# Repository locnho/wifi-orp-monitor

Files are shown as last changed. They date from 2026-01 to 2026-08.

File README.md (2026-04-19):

# WiFi Pool ORP Monitor Device

This project provides a WiFi Pool ORP Monitor device using the following parts:

  * Seeed Studio XIAO ESP32C6 with WiFi support external antenna
  * 0.96" LCD Display
  * Rotary Switch
  * Atlas Lab Grade GOLD ORP Probe
  * Atlas EZO ORP Circuit Board
  * Atlas EZO Carrier Board
  * Custom connection board to connect them
  * 3D print housing with nylon 2.5mm hex spacer/screws

**IMPORTANT:** For salt water pool, you must use the GOLD ORP type probe.

The device will send ORP reading from Atlas probe to a MQTT broker. By default it is configured to send ORP reading to AquaLinkD ORP. Though, you should be able to publish any message to MQTT broker.

# How To Assemble the ORP Monitor Device

After you have printed the mounting housing (from folder models), perform the following steps:

  1. Attach 35MM DIN rail bracket to base plate
  2. Attach some on 6 holes nylon spacer (3mm or so)
  3. Attach the Atlas EZO Carrier Board with some nylon spacer. Did not measured the spacer height.
  4. Attach the Atlas ORP Circuit Board
  5. Make a custom board to house the ESP32C6 with three JST connectors. Then drill holes using the 3D printed template. JST connectors are 3 pins, 4 pins and 5 pins. For the ESP32C6, it is attached to 2.54mm Female Pin Header Socket Connector. This allows connecting the rotary, LCD, and Atlas RS232 to the ESP32C6 board. All you need is Vcc, GND, Rx, Tx, I2C, and some digital pin. For pin, see the Ardiuno source code. Attach the external WiFi antenna. See the image below. This is the green board.
  6. Attach some nylon spacer (did not measuer the spacer height)
  7. Slide the side cover in. The total height should be equal to the cover height.
  8. Create connector wire and attach them
  9. Attach the LCD to the top board with some nylone screws (2mm screw)
  10. Screw in some nylon screws

Better to see images below.

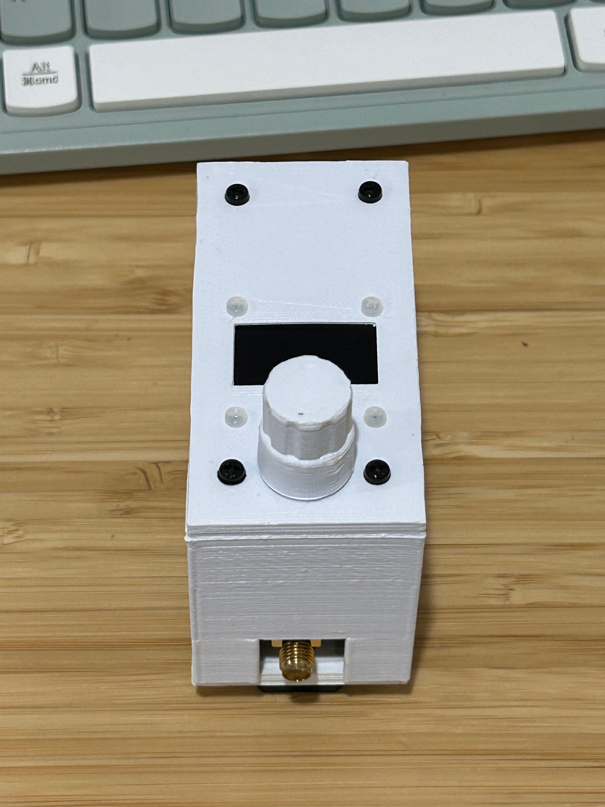
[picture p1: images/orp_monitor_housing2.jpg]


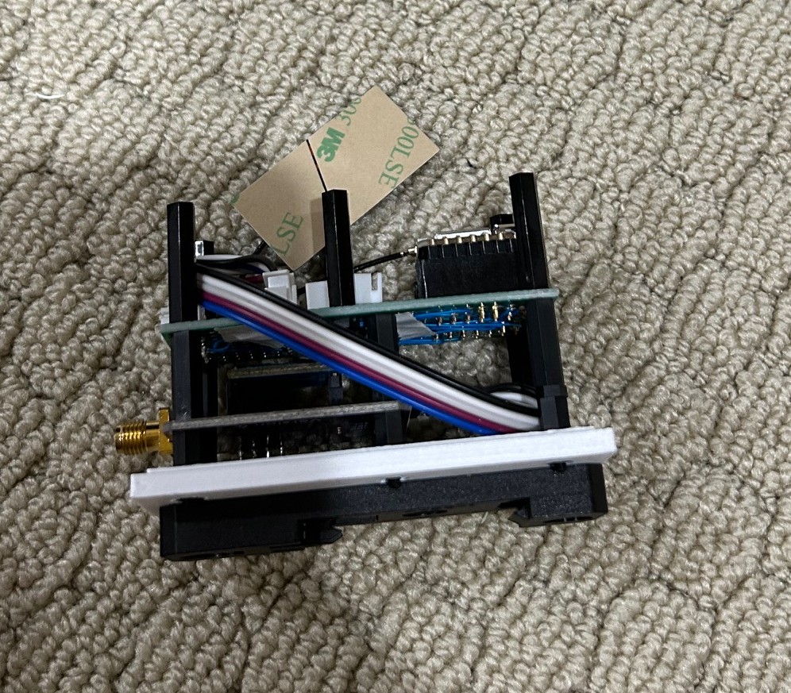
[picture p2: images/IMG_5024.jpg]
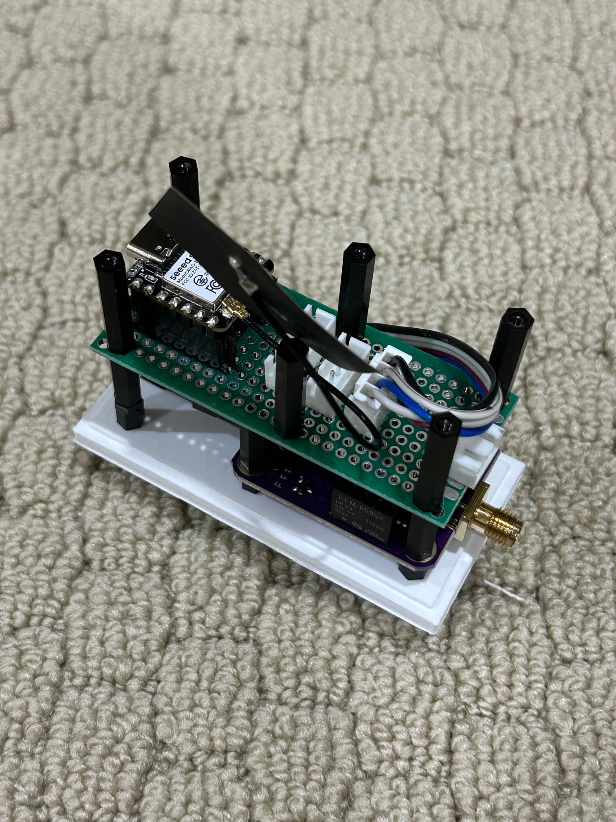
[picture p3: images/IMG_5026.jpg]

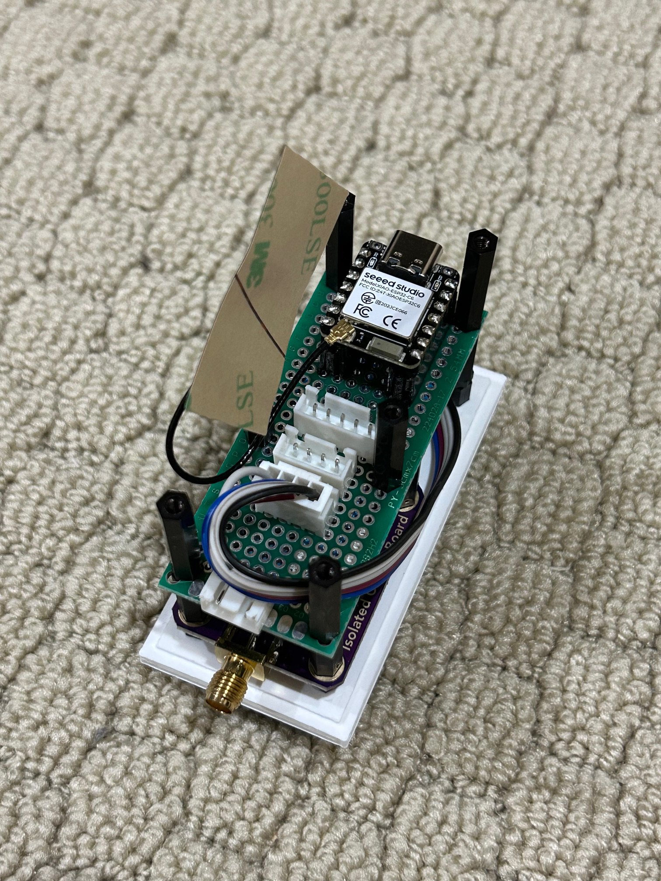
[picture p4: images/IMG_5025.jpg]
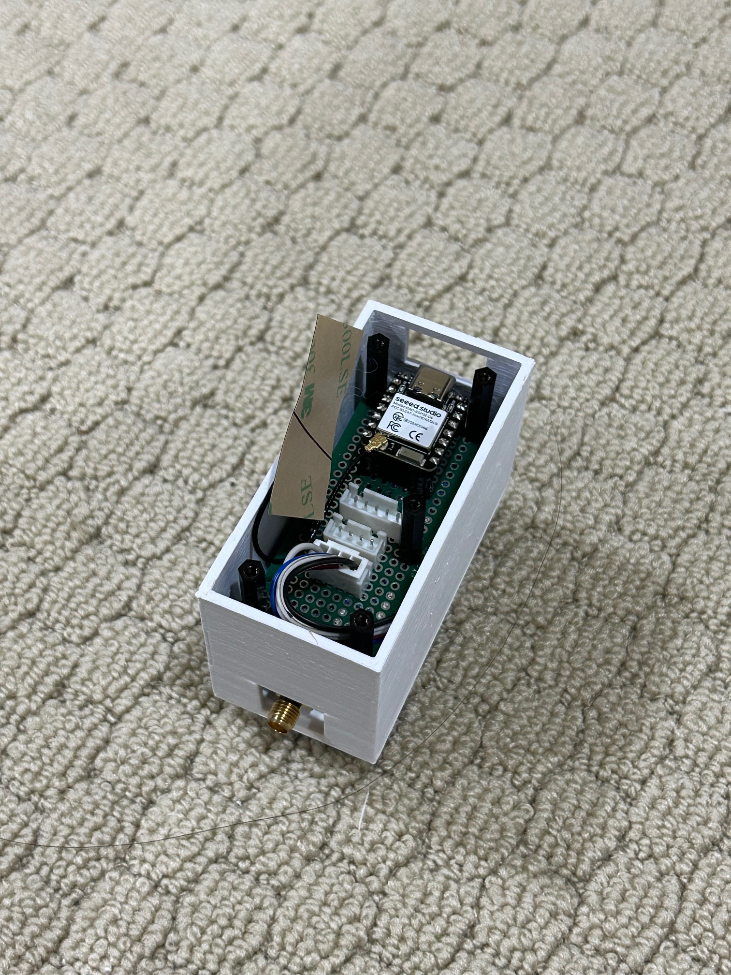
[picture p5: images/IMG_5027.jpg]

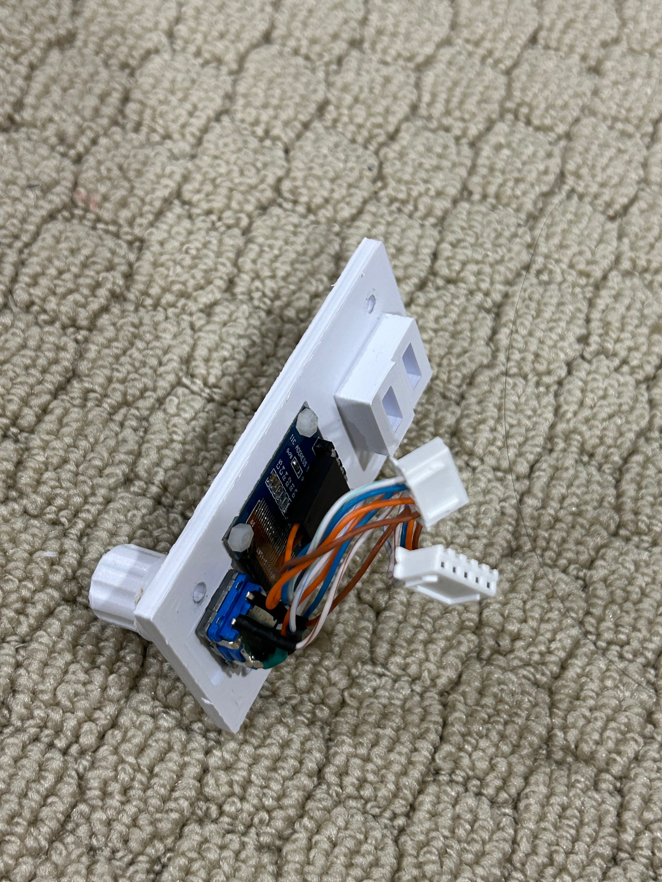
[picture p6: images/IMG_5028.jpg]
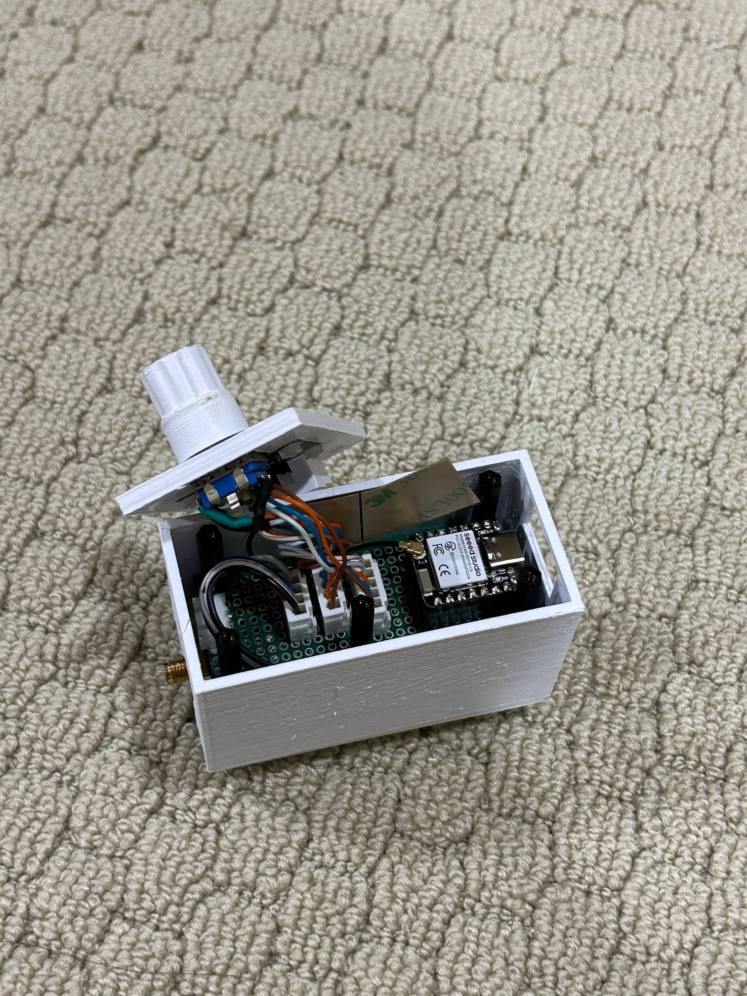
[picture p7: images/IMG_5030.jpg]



# How To Configure WiFi

After you have programmed the arduino code using Arduino IDE, perform the following steps:

  * Download the SmartConfig app. For iPhone, it is called "SmartConnect". Then start the app and set your WiFi password with the app.
  * On the ORP device, connect USB power
  * Press the button to enter menu
  * Select "WiFi Setup" and push the button
  * On the app, tap to start WiFi configuration

After this, wait around 2 to 3 minutes on the mobile app. This will configure the WiFi network and password.

# How To Configure System Setting

To configure system setting such as MQTT broker, ORP calibrate value, etc, open a browser and enter the IP address as ``http://<ip address>``.

You should see the below image. Configure the host name, MQTT Server name, user, password, port, and topic.

If the pump is not running, ORP value of 0.0 is reported using the ``MQTT Pump Topic``. If you want to always report ORP reading even if pump is not running, set to blank.

If your ORP calibration solution isn't 225 mV, change the ORP calibration value. Then click on the ``Submit`` button.

If you want this device to control the SWG percentage, check the box "Enable SWG Change:".

The Auto SWG algorithm is as follow:

 1. Delay for specified hours. This is configured via "SWG Control Delay Time (hrs)".
 2. Measure the ORP for at least specified hours. This is configured via "SWG Control Measure Time (hrs)". Until there is this specified measured time, the sample is not consider valid.
 3. After the sample is measured for specified hours, compute the sample average for that day.
 4. If the sample is below ORP target, schedule the SWG for next day.
 5. Once the avarge sample for that day is below specified target, schedule the SWG for next day.
 6. Run the SWG at specified percentage for specified time.

Given that the algorithm is based on day average, a date is required. The date is acquired using the NTP server. You must configures the NTP server and time zone.

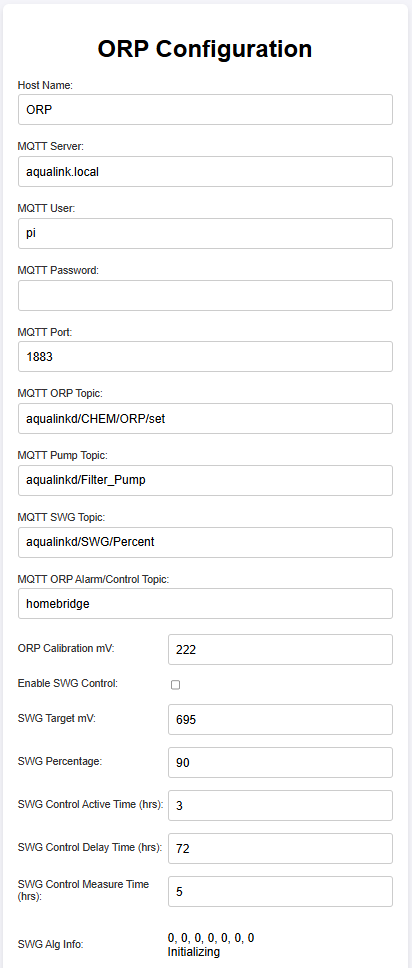
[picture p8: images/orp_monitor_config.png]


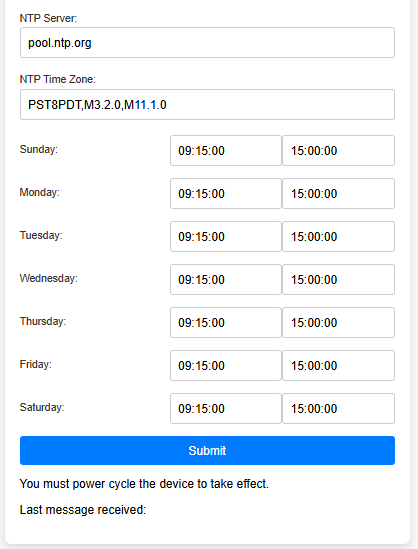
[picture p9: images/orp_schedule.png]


# How To Calibrate GOLD ORP Probe

To calibrate ORP probe, perform these steps:

  1. Push the button
  2. Select "CAL ORP" and push the knob to start ORP calibration

# How to Read the LCD Screen

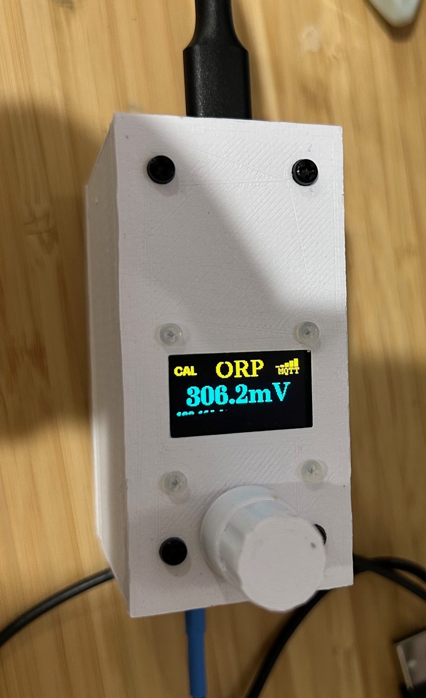
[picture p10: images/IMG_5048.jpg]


The "C" indicates that the ORP has been calibrated. If there is an X over it, then it is not calibrated.

The "P" indicates that the pump is running. If there is an X over it, then the pump is not running. This is based on MQTT message from MQTT pump topic. If the MQTT pump topic is blank, then it is assumed that the pump is always running.

The upper right WiFi bar indicate the WiFi RSSI strength.

The "MQTT" indicates that it is connected to a MQTT broker.

The first line reading shows:

  * ORP reading as from Atlas GOLD probe
  * Percentage of the SWG (if enabled support)

The second line reading shows:

  * ORP reading as computed
  * SWG percent this device configured the SWG via MQTT
  * Status code of the Auto SWG

The Status code of the Auto SWG are:

  * I - Initializing
  * D - Delay in-progress
  * S - Scheduling Auto SWG for next day
  * M - Measuring the ORP (per day) 
  * A - Auto SWG is active at specified percentage

The screen will turn off after some idle time. Press the button to show the screen.

Here is an image as reported via AquaLinkD.



If you want to disable 'Auto SWG', you can do the following:

  1. Disable via the web site configuration
  2. Disable via the MQTT Homebridge device or HomeKit using the 'Auto SWG'

Please note when disable from 'Auto SWG', it does not persist across a power cycle.

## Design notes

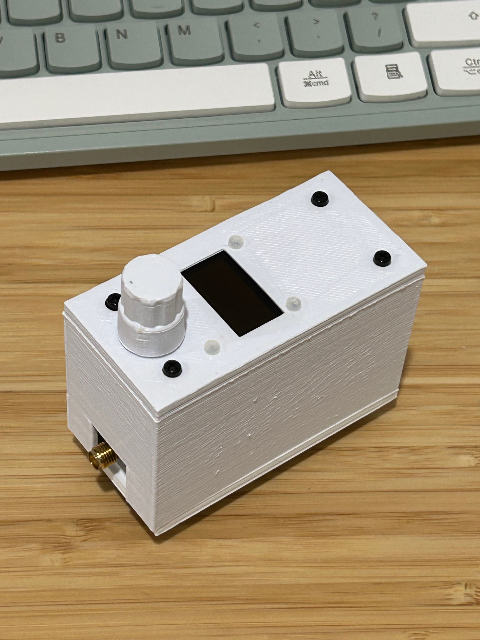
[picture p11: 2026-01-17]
images/orp_monitor_housing1.jpg

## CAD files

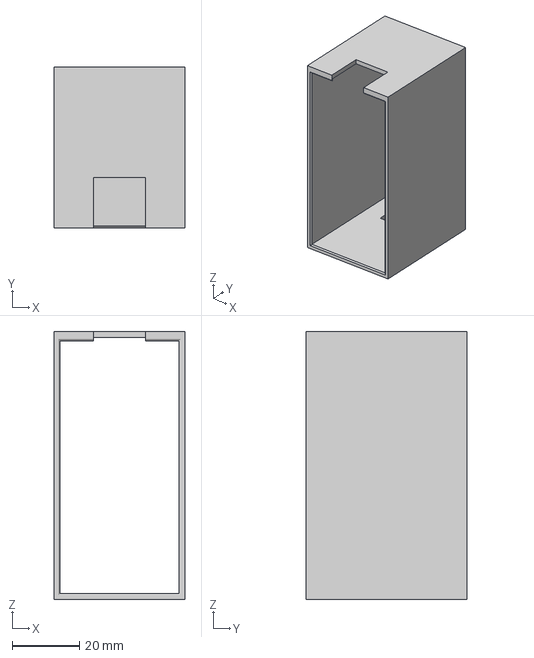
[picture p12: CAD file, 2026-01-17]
models/ORP-Side.3mf
39.0 x 48.0 x 80.0 mm

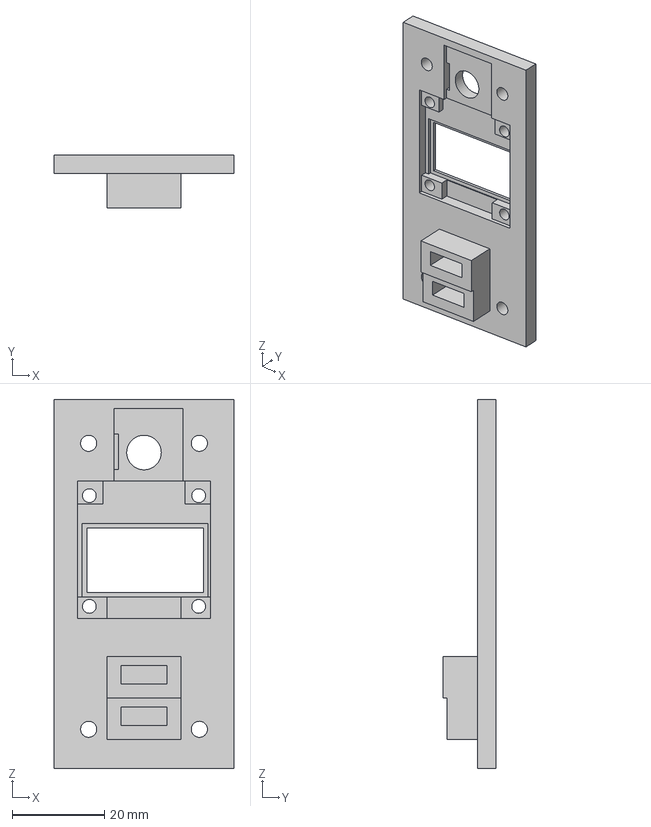
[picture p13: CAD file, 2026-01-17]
models/ORP-Top.3mf
39.0 x 11.5 x 80.0 mm

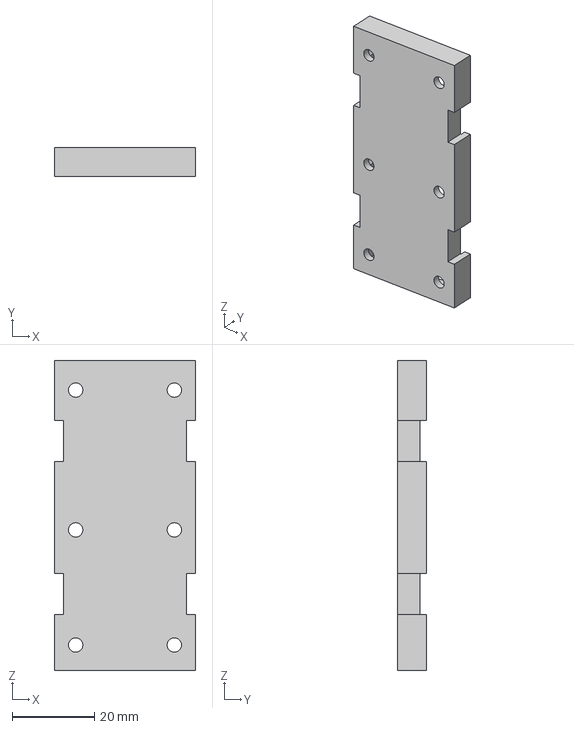
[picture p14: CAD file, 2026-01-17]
models/ORP-Drill-Plate.3mf
34.4 x 7.00 x 75.4 mm

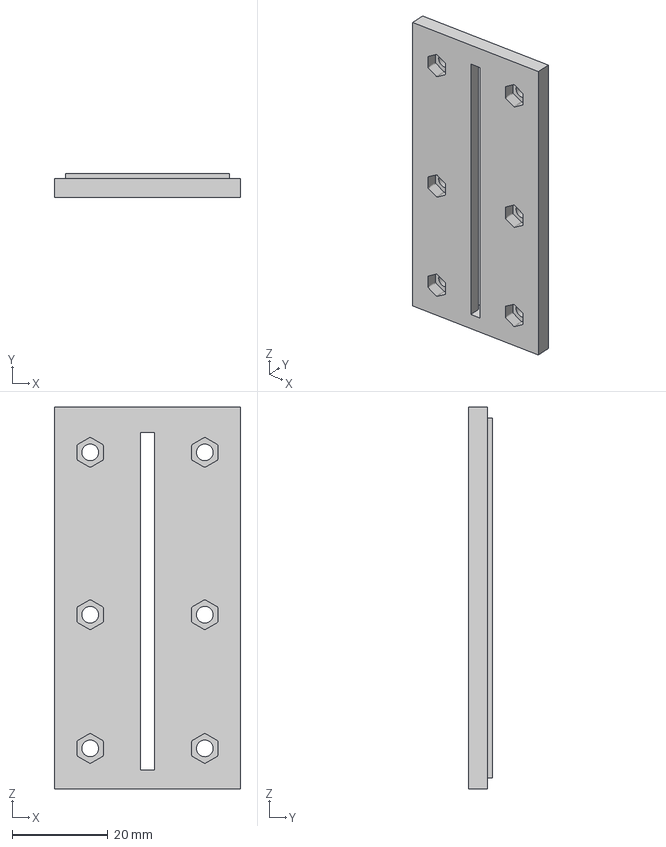
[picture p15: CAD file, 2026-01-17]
models/DIN-Rail-ORP-Base.3mf
39.0 x 5.00 x 80.0 mm

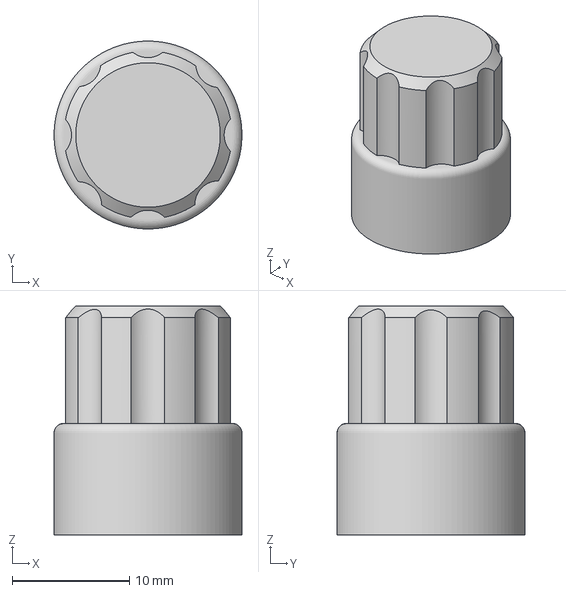
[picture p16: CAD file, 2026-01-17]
models/Rotary-Knob.3mf
16.0 x 16.0 x 19.5 mm

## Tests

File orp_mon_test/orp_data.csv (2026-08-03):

Date | orp | swg | alarm | ph
1770663612 | 574.7 | 55 | 1 | 0
1770663642 | 574.6 | 55 | 1 | 0
1770663672 | 574.4 | 55 | 1 | 0
1770663732 | 574.3 | 55 | 1 | 0
1770663762 | 574.4 | 55 | 1 | 0
1770663792 | 574.6 | 55 | 1 | 0
1770663822 | 574.4 | 55 | 1 | 0
1770663852 | 574.3 | 55 | 1 | 0
1770663882 | 574.4 | 55 | 1 | 0
1770663912 | 574.3 | 55 | 1 | 0
1770663942 | 573.9 | 55 | 1 | 0
1770663972 | 574.1 | 55 | 1 | 0
1770664002 | 573.8 | 55 | 1 | 0
1770664032 | 573.7 | 55 | 1 | 0
1770664092 | 573.6 | 55 | 1 | 0
1770664122 | 573.1 | 55 | 1 | 0
1770664152 | 573.3 | 55 | 1 | 0
1770664182 | 573.1 | 55 | 1 | 0
1770664212 | 573.2 | 55 | 1 | 0
1770664242 | 572.8 | 55 | 1 | 0
1770664272 | 572.9 | 55 | 1 | 0
1770664332 | 572.8 | 55 | 1 | 0
1770664362 | 572.7 | 55 | 1 | 0
1770664392 | 572.6 | 55 | 1 | 0
1770664422 | 572.5 | 55 | 1 | 0
1770664452 | 572.3 | 55 | 1 | 0
1770664482 | 572.2 | 55 | 1 | 0
1770664512 | 572.1 | 55 | 1 | 0
1770664542 | 572.0 | 55 | 1 | 0
1770664572 | 571.9 | 55 | 1 | 0
1770664602 | 571.7 | 55 | 1 | 0
1770664632 | 571.3 | 55 | 1 | 0
1770664692 | 571.2 | 55 | 1 | 0
1770664722 | 571.0 | 55 | 1 | 0
1770664752 | 570.8 | 55 | 1 | 0
1770664782 | 570.6 | 55 | 1 | 0
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

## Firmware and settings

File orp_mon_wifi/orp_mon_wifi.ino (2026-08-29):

/*
 * ORP Monitor
 *
 */
#define WIFI_SUPPORT 1
#define WIFI_EXTERNAL_ANTENNA 1

#if defined(WIFI_SUPPORT) && (defined(ARDUINO_SEEED_XIAO_ESP32C3) || defined(ARDUINO_ARCH_ESP32) || defined(ARDUINO_SEEED_XIAO_ESP32C6))
#else
  #undef WIFI_SUPPORT
#endif

#include "Button2.h"
#include "Rotary.h"
#include <U8g2lib.h>
#include <Wire.h>
#include <HardwareSerial.h>

#define DBG_SUPPORT 1         /* Print general debug information */
//#define DBG_STATUS 1        /* Print equivalent of menu on serial port */
//#define DBG_MQTT 1          /* Print MQTT messages */
#define DBG_ORP 1             /* Print ORP message */
//#define SKIP_MQTT_PUBLISH 1   /* Set to 1 to skip publish any MQTT message - use for testing without actual control SWG */

#if defined(DBG_SUPPORT)
  #define DBG_PRINT   Serial.print
  #define DBG_PRINTLN Serial.println
#else
  #define DBG_PRINT(x)
  #define DBG_PRINTLN(x)
#endif

#if defined(DBG_STATUS)
  #define STATUS_PRINT   Serial.print
  #define STATUS_PRINTLN Serial.println
#else
  #define STATUS_PRINT(x)
  #define STATUS_PRINTLN(x)
#endif

#if defined(DBG_ORP)
  #define ORP_PRINT   Serial.print
  #define ORP_PRINTLN Serial.println
#else
  #define ORP_PRINT(x)
  #define ORP_PRINTLN(x)
#endif

#if defined(DBG_MQTT)
  #define MQTT_PRINT   Serial.print
  #define MQTT_PRINTLN Serial.println
#else
  #define MQTT_PRINT(x)
  #define MQTT_PRINTLN(x)
#endif

#define FW_VERSION    "0.7"

//
// Rotary and Button
#define ROTARY_PIN1	2
#define ROTARY_PIN2	1
#define BUTTON_PIN	A0
#define CLICKS_PER_STEP   4   // this number depends on your rotary encoder 
Rotary rotary;
Button2 button;

//
// OELD
U8G2_SSD1306_128X64_NONAME_F_HW_I2C u8g2(U8G2_R0, /* reset=*/ U8X8_PIN_NONE);
int oled_addr = 0x3C;
bool oled_detected = 0;
unsigned long oled_idle_ts = 0;
bool oled_idle = 0;
unsigned long oled_refresh_ts = 0;
unsigned long oled_alive = 0;
#define OLED_IDLE_TIMEOUT_MS      (2*60000)
bool oled_screen_refresh = 0;

//
// Status message
char status_msg[40];
unsigned long status_msg_ts = 0;

//
// ORP Info
char orp_line[80];
int orp_line_cnt = 0;
float orp_reading = 0.0;
unsigned long ord_ts = 0;
int orp_caled = -1;
unsigned long orp_cal_ts = 0;
unsigned long orp_query_ts = 0;
enum ORP_STATE {
  OP_ORP_READING = 1,
  OP_ORP_CAL_INIT,
  OP_ORP_CAL_RESPONSE,
};
enum ORP_STATE orp_state = OP_ORP_READING;
HardwareSerial orp_serial(0);

//
// Operation State
enum OP_STATE {
  OP_NORMAL = 0,
  OP_MENU,
  OP_ORP_CAL,
  OP_WIFI_SETUP,
  OP_MQTT_CONNECT,
  OP_SETTING_INFO,
};

enum OP_STATE op_state = OP_NORMAL;

//
// WiFi
#if defined(WIFI_SUPPORT)
#include "sdkconfig.h"
#include "WiFi.h"
#include <ArduinoMDNS.h>
#include "time.h"
#include "esp_sntp.h"

typedef struct {
  uint32_t signature1;
  uint32_t signature2;
  char ssid[64];
  char password[64];
  char hostname[64];
  char mqtt_broker[64];
  char mqtt_topic[64];
  char mqtt_user[64];
  char mqtt_password[64];
  char mqtt_pump_topic[64];
  char mqtt_swg_topic[64];
  char mqtt_orp_alarm_topic[64];
  char mqtt_datetime_topic[64];
  int mqtt_port;
  int orp_cal_mV;
  int swg_control;          // 0 - disable; all other - enable
  int swg_orp_target;
  int swg_orp_target_max;
  int swg_orp_hysteresis;
  float swg_orp_std_dev;
  int swg_orp_interval;
  int swg_orp_guard;
  int swg_orp_pct[5];
  int swg_data_sample_time_sec;

  int start_schedule[7];
  int end_schedule[7];

  int swg_orp_active_time_hrs;
  int swg_orp_delay_time_hrs;
  int swg_orp_measure_time_start;
  int swg_orp_measure_time_end;
  char ntp_server[64];
  char ntp_tz[64];
} Setting_Info;

#define SIGNATURE1    0x57494649
#define SIGNATURE2    0x00000003
#define MQTT_BROKER_DEFAULT   "aqualink.local"
#define SSID_DEFAULT          ""
#define SSID_PW_DEFAULT       ""
#define MQTT_PW_DEFAULT       ""
#define MQTT_SUGGEST_BROKER_DEFAULT "aqualink.local"
#define MQTT_TOPIC_DEFAULT          "aqualinkd/CHEM/ORP/set"
#define MQTT_TOPIC_PUMP_DEFAULT     "aqualinkd/Filter_Pump"
#define MQTT_TOPIC_SWG_DEFAULT      "aqualinkd/SWG/Percent"
#define MQTT_TOPIC_DATETIME_DEFAULT "datetime"
#define MQTT_TOPIC_ORP_ALARM_DEFAULT "homebridge"
#define MQTT_USER_DEFAULT     "pi"
#define MQTT_PORT_DEFAULT     1883
#define HOSTNAME_DEFAULT      "ORP"
#define ORP_CAL_MV_DEFAULT    225
#define SWG_CONTROL_DEFAULT    90
#define START_SCHEDULE_DEFAULT    (9*60*60)
#define END_SCHEDULE_DEFAULT      (15*60*60)
#define NTP_SERVER_DEFAULT        "pool.ntp.org"
#define NTP_TZ_DEFAULT            "PST8PDT,M3.2.0,M11.1.0"
#define NTP_EPOCH_YEAR_OFFSET     1900

Setting_Info setting_info;

char mqtt_pump_topic_match[64];

long rssi = 0;
enum WIFI_STATE {
  OP_WIFI_IDLE = 1,
  OP_WIFI_SMARTCONFIG,
  OP_WIFI_WAIT_CONNECT,
};

#define ORP_PUBLISH_TIMEMS      3000
unsigned long mqtt_orp_publish_ts = 0;

enum WIFI_STATE wifi_state = OP_WIFI_IDLE;
unsigned long wifi_setup_ts = 0;
void mqtt_publish(int orp);
bool is_wifi_connected();
bool mqtt_is_subscribed();
bool mqtt_is_connected();
bool mqtt_is_connected_subscribed();

unsigned long setting_info_ts = 0;

bool mdns_ready = 0;
unsigned long mdns_ready_ts = 0;
WiFiUDP udp;
MDNS mdns(udp);

#endif /* WIFI_SUPPORT */

unsigned long mqtt_connect_ts = 0;
int mqtt_connect_first_time = 1;
int mqtt_pump_state = -1;
int mqtt_swg_pct = -1;
unsigned long mqtt_autoswg_ts = 0;
int mqtt_autoswg_ts_valid = 0;

//
// Serial Setup
void serial_setup()
{
  Serial.begin(115200);
  orp_serial.begin(9600);
}

//
// Status support functions
void set_status_msg(char *msg)
{
  strcpy(status_msg, msg);
  status_msg_ts = millis();
  DBG_PRINTLN(msg);
  oled_screen_refresh = 1;
}

void clear_status_msg()
{
  status_msg[0] = 0;
  status_msg_ts = 0;
  oled_screen_refresh = 1;
}

void check_status_msg_expired()
{
  if (status_msg[0] != 0 && (millis() - status_msg_ts) > 10000) {
    clear_status_msg();
    oled_screen_refresh = 1;
  }
}

//
// Button/Rotary Functions
void button_click(Button2& btn);
void button_rotate(Rotary& r);

void rotary_button_setup()
{
  rotary.begin(ROTARY_PIN1, ROTARY_PIN2, CLICKS_PER_STEP);
  rotary.setChangedHandler(button_rotate);
  button.begin(BUTTON_PIN);
  button.setTapHandler(button_click);
}

///////////////////////////////////////////////////////////////////////////////
// Data Samples Statistic
///////////////////////////////////////////////////////////////////////////////
#include "swganalyzer.h"
unsigned long orp_swg_ctl_chk_ts = 0;
int orp_swg_ctl_chk_ts_valid = 0;
SWGAnalyzerv3 swg_anlyzer;

struct tm *my_localtime()
{
  static struct tm timeinfo;
  
  if (getLocalTime(&timeinfo)) 
    return &timeinfo;
  timeinfo.tm_year = 2000;
  timeinfo.tm_mon = 0;
  timeinfo.tm_mday = 1;
  timeinfo.tm_hour = 0;
  timeinfo.tm_min = 0;
  timeinfo.tm_sec = 0;
  timeinfo.tm_wday = 0;
  return &timeinfo;
}

void orp_data_setup()
{
  swg_anlyzer.set_time_functions(millis, my_localtime);
  swg_anlyzer.setup();
  if (swg_anlyzer.get_alg_id() == 1)
    swg_anlyzer.setup_alg(setting_info.swg_data_sample_time_sec, setting_info.swg_orp_std_dev, setting_info.swg_orp_target,
                          setting_info.swg_orp_hysteresis, setting_info.swg_orp_interval, setting_info.swg_orp_guard,
                          setting_info.swg_orp_pct);
  else if (swg_anlyzer.get_alg_id() == 2)
    swg_anlyzer.setup_alg(setting_info.swg_orp_target, setting_info.swg_orp_active_time_hrs, setting_info.swg_orp_delay_time_hrs,
                          0, setting_info.swg_control > 0 ? setting_info.swg_orp_pct[0] : 0);
  else
    swg_anlyzer.setup_alg(setting_info.swg_orp_target, setting_info.swg_orp_target_max, setting_info.swg_orp_measure_time_start, setting_info.swg_orp_measure_time_end, setting_info.swg_control > 0 ? setting_info.swg_orp_pct[0] : 0);

  for (int i = 0; i < 7; i++) {
    swg_anlyzer.set_schedule(i, setting_info.start_schedule[i], setting_info.end_schedule[i]);
  }
  if (strlen(setting_info.ntp_server) > 0)
    swg_anlyzer.enable_datetime_check(1);
  // else if (strlen(setting_info.mqtt_datetime_topic) > 0)
  //   swg_anlyzer.enable_datetime_check(1);
  else
    swg_anlyzer.enable_datetime_check(0);
}

void orp_swg_ctrl_loop()
{
  int swg_pct;

  if (!orp_swg_ctl_chk_ts_valid) {
    orp_swg_ctl_chk_ts = millis();
    orp_swg_ctl_chk_ts_valid = 1;
  } else if ((millis() - orp_swg_ctl_chk_ts) <= 60000) {
    return;
  }

  if (!swg_anlyzer.is_scheduled()) {
    orp_swg_ctl_chk_ts = millis();
    mqtt_aswg_active_publish(0);
    return;
  }

  swg_pct = swg_anlyzer.get_swg_pct(mqtt_swg_pct);
  // mqtt_orp_alarm_publish(swg_anlyzer.is_alarmed());
  if (swg_pct >= 0) {
    swg_set(swg_pct);
  }
  mqtt_aswg_active_publish(swg_pct > 0 ? 1 : 0);
  orp_swg_ctl_chk_ts = millis();
}

//
// OELD functions
void clear_idle_timer()
{
  oled_idle = 0;
  oled_idle_ts = millis();
}

void oled_setup()
{
  Wire.begin();
  Wire.beginTransmission(oled_addr);
  int error = Wire.endTransmission();
  Wire.end();
  if (error == 0) {
    DBG_PRINTLN("OLED detected");
    oled_detected = 1;
    clear_status_msg();
  } else {
    DBG_PRINTLN("OLED not detected");
  }

  if (oled_detected) {
    u8g2.begin();
  }
}

void oled_clear()
{
  if (!oled_detected)
    return;
  u8g2.clear();
}

void oled_idle_check()
{
  if (!oled_detected)
    return;

  if (op_state != OP_NORMAL)
    return;

  if (!oled_idle) {
    if ((millis() - oled_idle_ts) >= OLED_IDLE_TIMEOUT_MS) {
      oled_idle = 1;
      oled_clear();
      DBG_PRINTLN("OLED idle");
    }
  }
}

void oled_wifi_update(int show_ip = 1)
{
#if defined(WIFI_SUPPORT)
  if (!oled_detected)
    return;

  u8g2.setFont(u8g2_font_helvB08_tf);
  int offset = 21;
  u8g2.drawStr(offset, 12, "P");
  u8g2.drawCircle(offset + 2, 8, 7);
  if (!mqtt_is_pump_on()) {
     u8g2.drawLine(offset - 3, 2, offset + 7, 14);
     u8g2.drawLine(offset - 2, 2, offset + 8, 14);
     u8g2.drawLine(offset - 4, 2, offset + 6, 14);
     u8g2.drawLine(offset - 3, 14, offset + 7, 2);
     u8g2.drawLine(offset - 2, 14, offset + 8, 2);
     u8g2.drawLine(offset - 4, 14, offset + 6, 2);
  }

  if (!is_wifi_connected())
    return;

  if (rssi >= -55) { 
    u8g2.drawBox(102,7,4,1);
    u8g2.drawBox(107,6,4,2);
    u8g2.drawBox(112,4,4,4);
    u8g2.drawBox(117,2,4,6);
    u8g2.drawBox(122,0,4,8);
  } else if (rssi < -55 & rssi > -65) {
    u8g2.drawBox(102,7,4,1);
    u8g2.drawBox(107,6,4,2);
    u8g2.drawBox(112,4,4,4);
    u8g2.drawBox(117,2,4,6);
    u8g2.drawFrame(122,0,4,8);
  } else if (rssi < -65 & rssi > -75) {
    u8g2.drawBox(102,8,4,1);
    u8g2.drawBox(107,6,4,2);
    u8g2.drawBox(112,4,4,4);
    u8g2.drawFrame(117,2,2,6);
    u8g2.drawFrame(122,0,4,8);
  } else if (rssi < -75 & rssi > -85) {
    u8g2.drawBox(102,8,4,1);
    u8g2.drawBox(107,6,4,2);
    u8g2.drawFrame(112,4,4,4);
    u8g2.drawFrame(117,2,4,6);
    u8g2.drawFrame(122,0,4,8);
  } else if (rssi < -85 & rssi > -96) {
    u8g2.drawBox(102,8,4,1);
    u8g2.drawFrame(107,6,4,2);
    u8g2.drawFrame(112,4,4,4);
    u8g2.drawFrame(117,2,4,6);
    u8g2.drawFrame(122,0,4,8);
  } else {
    u8g2.drawFrame(102,8,4,1);
    u8g2.drawFrame(107,6,4,2);
    u8g2.drawFrame(112,4,4,4);
    u8g2.drawFrame(117,2,4,6);
    u8g2.drawFrame(122,0,4,8);
  }

  if (show_ip) {
    u8g2.setFont(u8g2_font_helvB08_tf);
    IPAddress ip_address = WiFi.localIP();
    String ip_string = ip_address.toString();
    u8g2.drawStr(0, 54, ip_string.c_str());
  }

  if (mqtt_is_connected_subscribed()) {  
    u8g2.setFont(u8g2_font_courR08_tf);
    u8g2.drawStr(u8g2.getDisplayWidth() - u8g2.getStrWidth("MQTT"), 15, "MQTT");
  }
#endif
}

bool is_orp_reading_expired()
{
  if (ord_ts == 0)
    return 1;
  if ((millis() - ord_ts) > 3000)
    return 1;
  return 0;
}

void oled_orp_update()
{
  u8g2.setFont(u8g2_font_helvB08_tf);
  u8g2.drawStr(4, 12, "C");
  u8g2.drawCircle(7, 8, 7);
  if (orp_caled != 1) {
    int offset = 4;
    u8g2.drawLine(offset - 3, 2, offset + 7, 14);
    u8g2.drawLine(offset - 2, 2, offset + 8, 14);
    u8g2.drawLine(offset - 4, 2, offset + 6, 14);
    u8g2.drawLine(offset - 3, 14, offset + 7, 2);
    u8g2.drawLine(offset - 2, 14, offset + 8, 2);
    u8g2.drawLine(offset - 4, 14, offset + 6, 2);
  }
}

void oled_alive_update()
{
  if (oled_alive == 0) {
    u8g2.setFont(u8g2_font_crox5tb_tf);
    u8g2.drawStr(u8g2.getDisplayWidth() - u8g2.getStrWidth("."), u8g2.getDisplayHeight() - 1, ".");
    oled_alive = 1;
  } else {
    oled_alive = 0;
  }
}

void oled_title_update(int show_ip = 0)
{
  u8g2.setFont(u8g2_font_crox5tb_tf);
  u8g2.drawStr(8 * 5, 16, "ORP");

  oled_orp_update();
  oled_wifi_update(show_ip);
}

void oled_status_alive_update(int show_status = 1)
{
  oled_alive_update();

  if (!show_status) {
    return;
  }
  
  u8g2.setFont(u8g2_font_helvB08_tf);
  if (strlen(status_msg) > 0) {
    u8g2.drawStr(0, 63, status_msg);
  } else {
    char msg[40];
    const time_t time_val_sec = time(NULL);
    struct tm time_tm = *localtime(&time_val_sec);

    if (time_tm.tm_year + NTP_EPOCH_YEAR_OFFSET > 2000) {
      sprintf(msg, "%02d/%02d/%04d %02d:%02d:%02d", time_tm.tm_mon + 1, time_tm.tm_mday, time_tm.tm_year + NTP_EPOCH_YEAR_OFFSET, time_tm.tm_hour, time_tm.tm_min, time_tm.tm_sec);
      u8g2.drawStr(0, 63, msg);
    }
  }
}

void oled_title_update_print()
{
  if (orp_caled == 1) {
    STATUS_PRINT("CAL     ");
  } else {
    STATUS_PRINT("NOT CAL ");
  }

  if (mqtt_is_pump_on()) {
    STATUS_PRINT("PUMP ON  ");
  } else {
    STATUS_PRINT("PUMP OFF ");
  }

#if defined(WIFI_SUPPORT)
  if (is_wifi_connected()) {
    STATUS_PRINT("RSSI ");
    STATUS_PRINT(rssi);
    STATUS_PRINT(" ");
    if (mqtt_is_connected()) {
      STATUS_PRINT("MQTT    ");
    } else {
      STATUS_PRINT("NO MQTT ");
    }
    if (mqtt_is_subscribed()) {
      STATUS_PRINT("Subscribed     ");
    } else {
      STATUS_PRINT("NOT Subscribed ");
    }
    STATUS_PRINT(WiFi.localIP());
    STATUS_PRINT(" ");

    char msg[40];
    const time_t time_val_sec = time(NULL);
    struct tm time_tm = *localtime(&time_val_sec);

    if (time_tm.tm_year + NTP_EPOCH_YEAR_OFFSET > 2000) {
      sprintf(msg, "%02d/%02d/%04d %02d:%02d:%02d ", time_tm.tm_mon + 1, time_tm.tm_mday, time_tm.tm_year + NTP_EPOCH_YEAR_OFFSET, time_tm.tm_hour, time_tm.tm_min, time_tm.tm_sec);
      STATUS_PRINT("NTP ");
      STATUS_PRINT(msg);
    } else {
      STATUS_PRINT("NTP --/--/---- --:--:-- ");
    }
  }
#endif
}

void oled_status_alive_update_print()
{
  if (strlen(status_msg) > 0) {
    STATUS_PRINT(" ");
    STATUS_PRINT(status_msg);
  }
}

void oled_update_normal(bool now)
{
  char msg1[40];
  char msg2[40];

  if (now == 0 && (millis() - oled_refresh_ts) <= 1000)
    return;
  if (oled_idle) {
    return;
  }
  // if (!oled_screen_refresh) {
  //   return;
  // }

  oled_screen_refresh = 0;
  oled_refresh_ts = millis();

  oled_title_update_print();
  int swg_pct;
  if (mqtt_swg_pct < 0)
    swg_pct = 0;
  else
    swg_pct = mqtt_swg_pct;
  if (is_orp_reading_expired()) {
    sprintf(msg1, "---- ");
    sprintf(msg2, "----   %d%% ", swg_pct);
  } else {
    sprintf(msg1, "%0.1f ", orp_reading);
    sprintf(msg2, "%0.1f   %d%% ", orp_reading, swg_pct);
  }
  STATUS_PRINT(msg1);
  STATUS_PRINT(msg2);
  STATUS_PRINT(swg_anlyzer.get_last_orp());
  STATUS_PRINT(swg_anlyzer.get_last_swg_pct());
  oled_status_alive_update_print();
  STATUS_PRINTLN("");

  if (!oled_detected)
    return;

  u8g2.clearBuffer();
  oled_title_update();
  oled_status_alive_update();

  u8g2.setFont(u8g2_font_ncenR18_tf);
  if (u8g2.getStrWidth(msg2) >= 128)
    u8g2.setFont(u8g2_font_ncenR14_tf);
  int x = (u8g2.getDisplayWidth()-10 - u8g2.getStrWidth(msg2)) / 2;
  int x2 = u8g2.getStrWidth(msg1);
  if (setting_info.swg_control > 0)
    u8g2.drawButtonUTF8(5 + x, 34, U8G2_BTN_BW0, u8g2.getDisplayWidth()-5*2,  0,  0, msg2);
  else
    u8g2.drawButtonUTF8(5 + x, 34, U8G2_BTN_BW0, u8g2.getDisplayWidth()-5*2,  0,  0, msg1);
  u8g2.setFont(u8g2_font_ncenR08_tf);
  u8g2.drawStr(5 + x + x2, 25, "m");
  u8g2.drawStr(5 + x + x2, 34, "V");

  u8g2.setFont(u8g2_font_ncenR12_tf);
  float v1 = swg_anlyzer.get_last_orp();
  int v2 = swg_anlyzer.get_last_swg_pct();
  sprintf(msg1, "%0.1f", v1);
  if (swg_anlyzer.is_alarmed())
    sprintf(msg2, "%0.1f   Alarm", v1);
  else
    sprintf(msg2, "%0.1f   %d%%  ", v1, v2);
  x = (u8g2.getDisplayWidth()-10 - u8g2.getStrWidth(msg2)) / 2;
  x2 = u8g2.getStrWidth(msg1);
  u8g2.drawButtonUTF8(5 + x, 48 + 2, U8G2_BTN_BW0, u8g2.getDisplayWidth()-5*2,  0,  0, msg2);
  sprintf(msg2, "%c", swg_anlyzer.get_orp_code_char_str());
  u8g2.drawButtonUTF8(u8g2.getDisplayWidth() - u8g2.getStrWidth(msg2) - 1, 48 + 2, U8G2_BTN_BW0, u8g2.getDisplayWidth()-5*2,  0,  0, msg2);
  u8g2.setFont(u8g2_font_ncenR08_tf);
  u8g2.drawStr(5 + x + x2 + 1, 39 + 2, "m");
  u8g2.drawStr(5 + x + x2 + 1, 48 + 2, "V");

  u8g2.sendBuffer();
}

int menu_index = 0;
#if defined(WIFI_SUPPORT)
  #define MENU_TOTAL 4
  #define MENU_ORP_INDEX 0
  #define MENU_WIFI_INDEX 1
  #define MENU_SETTING_INFO_INDEX 2
  #define MENU_EXIT_INDEX 3
  char *menu_text[MENU_TOTAL] = {
    "CAL ORP",
    "WiFi Setup",
    "System Info",
    "Exit"
  };
#else
  #define MENU_TOTAL 2
  #define MENU_ORP_INDEX 0
  #define MENU_EXIT_INDEX 1
  #define MENU_WIF_INDEX  128
  #define MENU_SETTING_INFO_INDEX 127
  char *menu_text[MENU_TOTAL] = {
    "CAL ORP",
    "Exit"
  };
#endif

void oled_update_menu()
{
  char text[30];

  if ((millis() - oled_refresh_ts) <= 500)
    return;
  oled_refresh_ts = millis();

  oled_title_update_print();
  for (int i = 0; i < MENU_TOTAL; i++) {
    if (i == menu_index) {
      DBG_PRINT("[");
      DBG_PRINT(menu_text[i]);
      DBG_PRINTLN("]");
    } else {
      DBG_PRINTLN(menu_text[i]);
    }
  }
  oled_status_alive_update_print();

  if (!oled_detected)
    return;

  u8g2.clearBuffer();

  oled_title_update(0);

  u8g2.setFont(u8g2_font_helvB08_tf);
  for (int i = 0; i < MENU_TOTAL; i++) {
    sprintf(text, " %s", menu_text[i]);
    if (i == menu_index)
      u8g2.drawButtonUTF8(5, 25 + 12 * i, U8G2_BTN_INV, u8g2.getDisplayWidth()-5*2, 0, 1, text);
    else
      u8g2.drawButtonUTF8(5, 25 + 12 * i, U8G2_BTN_BW0, u8g2.getDisplayWidth()-5*2, 0, 1, text);
  }

  u8g2.sendBuffer();
}

int oled_update_setting_info()
{
#if defined(WIFI_SUPPORT)
  char msg[30];

  if ((millis() - oled_refresh_ts) <= 500)
    return 0;
  oled_refresh_ts = millis();

  if ((millis() - setting_info_ts) >= 30000) {
    return 1;
  }

  oled_title_update_print();
  oled_status_alive_update_print();
  DBG_PRINT("SSID");
  DBG_PRINTLN(setting_info.ssid);
  DBG_PRINTLN(setting_info.hostname);
  DBG_PRINTLN(WiFi.localIP());

  if (!oled_detected)
    return 0;

  u8g2.clearBuffer();

  oled_title_update(0);
  oled_status_alive_update(0);

  //u8g2.setFont(u8g2_font_helvB08_tf);
  u8g2.setFont(u8g2_font_courB08_tf);
  u8g2.drawStr(0, 24, setting_info.ssid);
  sprintf(msg, "FW %s RSSI %d", FW_VERSION, WiFi.RSSI());
  u8g2.drawStr(0, 32, msg);
  u8g2.drawStr(0, 40, setting_info.hostname);
  IPAddress ip_address = WiFi.localIP();
  String ip_string = ip_address.toString();
  u8g2.drawStr(0, 48, ip_string.c_str());
  sprintf(msg, "ORP CAL %dmV", setting_info.orp_cal_mV);
  u8g2.drawStr(0, 56, msg);
#if defined(WIFI_EXTERNAL_ANTENNA)
  u8g2.drawStr(0, 64, "Antenna External");
#else
  u8g2.drawStr(0, 64, "Antenna Internal");
#endif

  u8g2.sendBuffer();
  return 0;
#else
  return 1;
#endif
}

void oled_update_orp()
{
  if ((millis() - oled_refresh_ts) <= 500)
    return;
  oled_refresh_ts = millis();

  oled_title_update_print();
  switch (orp_state) {
  case OP_ORP_CAL_INIT:
  case OP_ORP_CAL_RESPONSE:
    DBG_PRINTLN("ORP CAL...");
    break;
  }
  oled_status_alive_update_print();

  if (!oled_detected)
    return;

  u8g2.clearBuffer();

  oled_title_update();
  oled_status_alive_update();

  u8g2.setFont(u8g2_font_helvB08_tf);
  u8g2.drawStr(0, 32, "ORP calibrate...");

  u8g2.sendBuffer();
}

void oled_update_wifi()
{
#if defined(WIFI_SUPPORT)
  if ((millis() - oled_refresh_ts) <= 500)
    return;
  oled_refresh_ts = millis();

  oled_title_update_print();
  switch (wifi_state) {
  case OP_WIFI_SMARTCONFIG:
  case OP_WIFI_WAIT_CONNECT:
    DBG_PRINTLN("WiFi...");
    break;
  case OP_WIFI_IDLE:
    break;
  }
  oled_status_alive_update_print();

  if (!oled_detected)
    return;

  u8g2.clearBuffer();

  oled_title_update();
  oled_status_alive_update();

  u8g2.setFont(u8g2_font_helvB08_tf);
  u8g2.drawStr(0, 32, "WiFi Setup...");

  u8g2.sendBuffer();
#endif /* WIF_SUPPORT */
}

void oled_update_mqtt_connect(int now)
{
#if defined(WIFI_SUPPORT)
  if (!now && (millis() - oled_refresh_ts) <= 500)
    return;
  oled_refresh_ts = millis();

  oled_title_update_print();
  switch (wifi_state) {
  case OP_WIFI_SMARTCONFIG:
  case OP_WIFI_WAIT_CONNECT:
    DBG_PRINTLN("WiFi...");
    break;
  case OP_WIFI_IDLE:
    break;
  }
  oled_status_alive_update_print();

  if (!oled_detected)
    return;

  u8g2.clearBuffer();

  oled_title_update();
  oled_status_alive_update();

  u8g2.setFont(u8g2_font_helvB08_tf);
  u8g2.drawStr(0, 32, "MQTT connect...");

  u8g2.sendBuffer();
#endif /* WIF_SUPPORT */
}
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
void loop()
{
  rotary.loop();
  button.loop();
  orp_loop();
  mqtt_loop();
  web_loop();
  mdns_loop();
  ntp_loop();
  orp_swg_ctrl_loop();

  switch (op_state) {
  case OP_MENU:
    oled_update_menu();
    break;
  case OP_ORP_CAL:
    if (orp_cal_loop()) {
      op_state = OP_NORMAL;
      clear_idle_timer();
    }
    oled_update_orp();
    break;
  case OP_WIFI_SETUP:
    if (wifi_loop()) {
      op_state = OP_NORMAL;
      clear_idle_timer();
    }
    oled_update_wifi();
    break;
  case OP_MQTT_CONNECT:
    if (mqtt_connect()) {
      op_state = OP_NORMAL;
      clear_idle_timer();
    }
    break;
  case OP_SETTING_INFO:
    if (oled_update_setting_info()) {
      op_state = OP_NORMAL;
      clear_idle_timer();
    }
    break;
  default:
    oled_update_normal(0);
    break;
  }
  
  oled_idle_check();
  check_status_msg_expired();
  wifi_link_chk_loop();
}

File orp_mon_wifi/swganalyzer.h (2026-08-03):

#ifndef SWG_ANALYZER_H
#define SWG_ANALYZER_H  1

#define MAX_ORP_DATA                (15*60)
#define SWG_ORP_STD_DEV_DEFAULT     2.5
#define SWG_ORP_DEFAULT             700
#define SWG_ORP_HYSTERESIS_DEFAULT  10
#define SWG_ORP_INTERVAL_DEFAULT    15
#define SWG_ORP_GUARD_DEFAULT       5
#define SWG_ORP_PCT0_DEFAULT        15
#define SWG_ORP_PCT1_DEFAULT        25
#define SWG_ORP_PCT2_DEFAULT        50
#define SWG_ORP_PCT3_DEFAULT        75
#define SWG_ORP_PCT4_DEFAULT        100
#define SWG_DATA_SAMPLE_TIME_SEC_DEFAULT (5*60)
#define SWG_ORP_MAX_DEFAULT         720

class SWGAnalyzer {
public:
  SWGAnalyzer();
  void setup();
  void setup_alg(int sample_time_sec, float std_dev, int orp_target_val, int orp_target_hysteresis_val, int orp_target_interval, int orp_target_guard, int orp_pct_val[5]);
  void orp_add(int val,  bool swg_active);
  int get_swg_pct(int curr_swg_pct);
  int get_alg_id() { return 1; }

  int get_orp_target() { return orp_target; }
  int get_last_orp() { return last_orp; };
  int get_last_swg_pct() { return last_orp_pct; };

  void enable_datetime_check(int enable);
  int is_scheduled();
  int is_alarmed() { return alarm; }
  void set_schedule(int day_num, int start, int end);

  void set_time_functions(unsigned long (*millis_cb_f)(), struct tm * (*localtime_cb_f)());

protected:
  unsigned long (*millis_cb)();
  struct tm * (*localtime_cb)();

  int orp_target;
  int orp_target_max;
  int last_orp;
  int last_orp_pct;
  int alarm;

  //
  // Scheduling
  int date_check;
  unsigned int start_time[7];
  unsigned int end_time[7];

  //
  // Alg variables
  int orp_data[MAX_ORP_DATA];
  unsigned long orp_data_ts[MAX_ORP_DATA];
  char orp_data_valid[MAX_ORP_DATA];
  int orp_data_curr;
  int max_sample;
  unsigned long orp_sample_time_ms;

  float orp_std_dev;
  int orp_hysteresis;
  int orp_interval;
  int orp_guard;
  int orp_pct[5];
  int orp_low_bound;
  int active_guard;

  int orp_std_deviation(float &std_dev, float &mean);
};

#define ORP_DAY_STATE_INIT          0 
#define ORP_DAY_STATE_DELAY         1   
#define ORP_DAY_STATE_MEASURE       2
#define ORP_DAY_STATE_SCHEDULE_SWG  3
#define ORP_DAY_STATE_ACTIVE_SWG    4

#define SWG_ORP_ACTIVE_TIME_HRS_DEFAULT     3
#define SWG_ORP_DELAY_TIME_HRS_DEFAULT      (3 * 24)
#define SWG_ORP_MEASURE_TIME_HRS_DEFAULT    5
#define SWG_ORP_MEASURE_TIME_START_DEFAULT  0
#define SWG_ORP_MEASURE_TIME_END_DEFAULT    0

#define ORP_DAY_RC_INIT                     1
#define ORP_DAY_RC_SCHEDULE_SWG_COMPLETE    2
#define ORP_DAY_RC_SCHEDULE_SWG_WAITING     3
#define ORP_DAY_RC_MEASURING                4
#define ORP_DAY_RC_MEAS_COMPLETE            5
#define ORP_DAY_RC_MEAS_DELAY_FOR_DAY       6
#define ORP_DAY_RC_MEAS_DELAY               7
#define ORP_DAY_RC_ACT_SWG_COMPLETE         8
#define ORP_DAY_RC_ACT_SWG                  9
#define ORP_DAY_RC_DELAY_COMPLETE           10
#define ORP_DAY_RC_DELAY                    11


#define TOTAL_NUM_DAYS_SAMPLE               7

class SWGAnalyzerv2 : public SWGAnalyzer {
public:
  SWGAnalyzerv2();
  void setup();
  void setup_alg(int orp_day_cfg_target_val, int orp_day_cfg_swg_time_hours, int orp_day_cfg_delay_time_hours, int orp_day_cfg_measure_time_hours, int orp_pct_val);
  void setup_alg(int sample_time_sec, float std_dev, int orp_target_val, int orp_target_hysteresis_val, int orp_target_interval, int orp_target_guard, int orp_pct_val[5]);
  void orp_add(int val,  bool swg_active);
  int get_swg_pct(int curr_swg_pct);
  int get_alg_id() { return 2; }

  int get_orp_day_avg(int day) { return orp_day_avg[day]; }
  int get_orp_day_state() { return orp_day_state; }
  int get_orp_day_reason_code() { return orp_day_reason_code; }
  unsigned long get_orp_day_delay_ts_ms() { return orp_day_delay_ts_ms; }
  int get_orp_day_curr() { return orp_day_curr; }
  void set_orp_pct_val(int orp_pct_val) { orp_pct[0] = orp_pct_val; }
  char get_orp_code_char_str();

  float get_remain_active_hrs();
  float get_remain_delay_hrs();
  float get_remain_measure_hrs();

protected:
  //
  // 7 day scheduling
  int orp_day_sum[TOTAL_NUM_DAYS_SAMPLE];
  int orp_day_total[TOTAL_NUM_DAYS_SAMPLE];
  int orp_day_avg[TOTAL_NUM_DAYS_SAMPLE];
  int orp_day_swg_wkday[TOTAL_NUM_DAYS_SAMPLE];
  unsigned long orp_day_measured_time[TOTAL_NUM_DAYS_SAMPLE];
  unsigned long orp_day_measured_ts[TOTAL_NUM_DAYS_SAMPLE];
  bool orp_day_swg_act[TOTAL_NUM_DAYS_SAMPLE];
  int orp_day_curr;
  int orp_day_state;

  bool orp_day_swg_active_time_valid;
  unsigned long orp_day_swg_active_time_st;
  unsigned long orp_day_swg_active_time_ms;
  unsigned long orp_day_delay_ts_ms;
  unsigned long orp_day_measure_ts_ms;
  unsigned long orp_day_cfg_swg_time_ms;
  unsigned long orp_day_cfg_delay_time_ms;
  bool orp_day_measure_time_valid;
  unsigned long orp_day_measure_time_st;
  unsigned long orp_day_measure_time_ms;
  unsigned long orp_day_cfg_measure_time_ms;
  int orp_day_schedule_day;
  int orp_day_reason_code;
};

class SWGAnalyzerv3 : public SWGAnalyzerv2 {
public:
  SWGAnalyzerv3();
  void setup_alg(int orp_day_cfg_target_val, int orp_day_max_cfg_target_val, int orp_day_cfg_measure_time_start, int orp_day_cfg_measure_time_end, int orp_pct_val);
  void setup_alg(int sample_time_sec, float std_dev, int orp_target_val, int orp_target_hysteresis_val, int orp_target_interval, int orp_target_guard, int orp_pct_val[5]) { }
  void orp_add(int val,  bool swg_active);
  int get_alg_id() { return 3; }
  int get_swg_pct(int curr_swg_pct);

  unsigned int swg_start_time;
  unsigned int swg_end_time;

};

#endif

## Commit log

2026-01-17 Init ORP monitor source, models, instruction
    Initial ORP monitor Arduino source code, 3D models housing, and instruction.
    [DIN-Rail-ORP-Base.3mf, ORP-Drill-Plate.3mf, ORP-Side.3mf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]
2026-02-04 Add display FW version/Fix display system info screen
    [orp_mon_wifi.ino]
2026-02-21 Fix ORP percent/HTML receive message
    Fix ORP percent array out of bound.
    Fix receive message truncated.
    Update version to 0.2
    [orp_mon_wifi.ino]
2026-03-24 Add support to ignore pump
2026-04-19 Auto SWG with 7 day monitor
    This update support monitor ORP based on 7 days sample using day averaging.
    The general algorithm:
    1. After SWG active, delay for X days (X is configurable)
    2. Sample the ORP per day.
    3. If the sample is below target mV, schedule SWG for next day.
    4. Schedule the SWG for specified hours (configurable)
    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
    [orp_data.csv]
2026-05-01 Fix Auto SWG
    * If SWG active, move to start of delay state.
    * Set Auto SWG topic update every 15 seconds
    [orp_data.csv]
2026-08-03 Update algorithms and simulation code
    [orp_data.csv]
2026-10-15 Add RS485/Serial Print
    - Add parsing RS485 (but not enabled by default). This allows future support without MQTT server.
    - Add print ORP reading and etc on USB serial (not fully tested).
    - Change to retain ORP value in swganalyzer when update over the web
    The above change is currently under testing.
